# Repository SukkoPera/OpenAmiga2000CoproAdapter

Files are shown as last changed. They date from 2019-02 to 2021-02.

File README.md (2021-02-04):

# OpenAmiga2000CoproAdapter
OpenAmiga2000CoproAdapter is an Open Hardware adapter that allows installing the main processor of a Commodore Amiga 2000 computer in the co-processor slot.

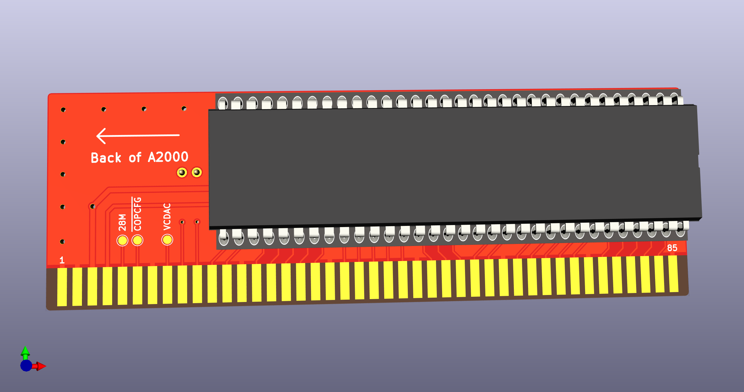
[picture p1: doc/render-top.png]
Board


### Summary
OpenAmiga2000CoproAdapter is an adapter that allows installing the main processor of a Commodore Amiga 2000 computer in the co-processor slot, based on [work by kipper2k](http://eab.abime.net/showthread.php?t=89604). It is mainly useful to mount TerribleFire and other accelerator cards without having to remove the floppy drive tray and without having them bump into your MegaChip, in case.

The adapter is very similar to the original, except that I skipped the INT7 and the A600 NMI circuits. Those are not needed for TerribleFire cards and for most other boards (I think they are for Vampires only). I carried over the INT2/OVR header, since the former is needed for the TF530. I have also introduced solder jumpers for the FR0-2 signals: those are not connected on kipper2k's board, I don't know why and it works well anyway, but I thought they wouldn't hurt as they will be open by default.

You may be able to install this without removing the original CPU by cutting the E jumper and closing the BOSS one.

This is a slightly expensive board to manufacture because it exceeds the 10x10cm limit that cheap fab houses impose, because it needs gold-plating for better contact and resistance to repeated insertions/removals, and because the edge connector should be beveled to ease insertion. These are the recommended settings if you want to get the boards made.

### Installation
**Please be very careful when plugging this board** in the co-processor slot: there is an arrow on the board, **it must point to the back of the Amiga**. Plugging this adapter backwards will damage your CPU/accelerator card, as some pins of the CPU slot carry +12V!

When this board is installed, most likely the original 68000 socket must be left empty unless you cut the E jumper and close the BOSS jumper, though this ultimately depends on the particular card you will be installing.

### License
The OpenAmiga2000CoproAdapter documentation, including the design itself, is copyright &copy; SukkoPera 2018-2019.

OpenAmiga2000CoproAdapter is Open Hardware licensed under the [CERN OHL v. 1.2](http://ohwr.org/cernohl).

You may redistribute and modify this documentation under the terms of the CERN OHL v.1.2. This documentation is distributed *as is* and WITHOUT ANY EXPRESS OR IMPLIED WARRANTIES whatsoever with respect to its functionality, operability or use, including, without limitation, any implied warranties OF MERCHANTABILITY, SATISFACTORY QUALITY, FITNESS FOR A PARTICULAR PURPOSE or infringement. We expressly disclaim any liability whatsoever for any direct, indirect, consequential, incidental or special damages, including, without limitation, lost revenues, lost profits, losses resulting from business interruption or loss of data, regardless of the form of action or legal theory under which the liability may be asserted, even if advised of the possibility or likelihood of such damages.

A copy of the full license is included in file [LICENSE.pdf](LICENSE.pdf), please refer to it for applicable conditions. In order to properly deal with its terms, please see file [LICENSE_HOWTO.pdf](LICENSE_HOWTO.pdf).

The contact points for information about manufactured Products (see section 4.2) are listed in file [PRODUCT.md](PRODUCT.md).

Any modifications made by Licensees (see section 3.4.b) shall be recorded in file [CHANGES.md](CHANGES.md).

The Documentation Location of the original project is https://github.com/SukkoPera/OpenAmiga2000CoproAdapter/.

### Support the Project
Since the project is open you are free to get the PCBs made by your preferred manufacturer, however in case you want to support the development, you can order them from PCBWay through this link:

PCB from PCBWay (https://www.pcbway.com/project/shareproject/OpenAmiga2000CoproAdapter_V3.html)

You get cheap, professionally-made and good quality PCBs, I get some credit that will help with this and [other projects](https://www.pcbway.com/project/member/shareproject/?bmbid=41100). You won't even have to worry about the various PCB options, it's all pre-configured for you!

Also, if you still have to register to that site, [you can use this link](https://www.pcbway.com/setinvite.aspx?inviteid=41100) to get some bonus initial credit (and yield me some more).

Again, if you want to use another manufacturer, feel free to, don't feel obligated :). But then you can buy me a coffee if you want:

<a href='https://ko-fi.com/L3L0U18L' target='_blank'>Buy Me a Coffee at ko-fi.com</a>

### Get Help
If you need help or have questions, you can join [the official Telegram group](https://t.me/joinchat/HUHdWBC9J9JnYIrvTYfZmg).

### Thanks
Thanks to kipper2k, of course :).

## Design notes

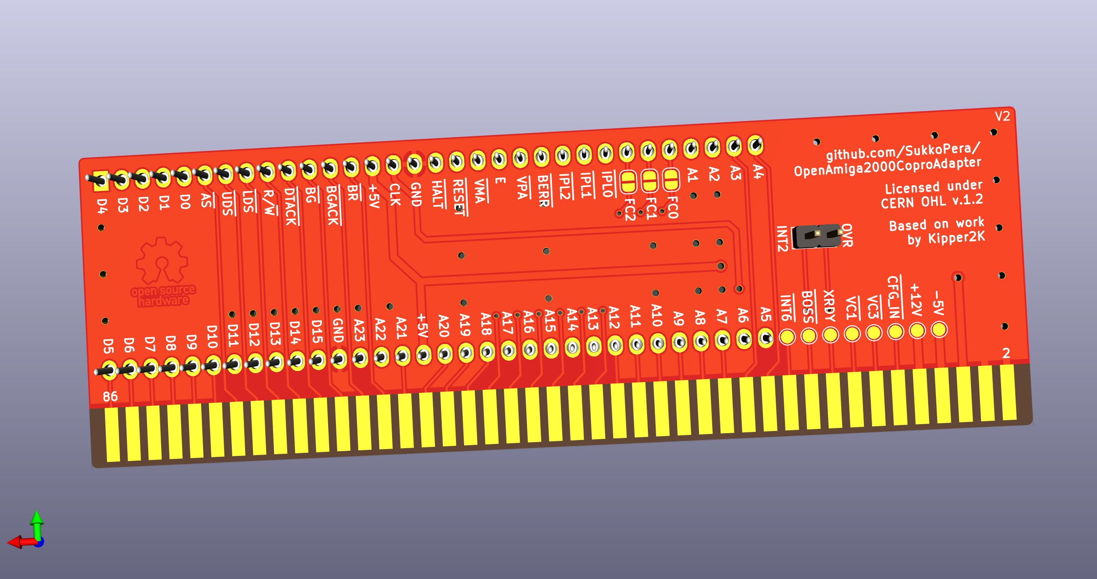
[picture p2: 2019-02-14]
doc/render-bottom.png

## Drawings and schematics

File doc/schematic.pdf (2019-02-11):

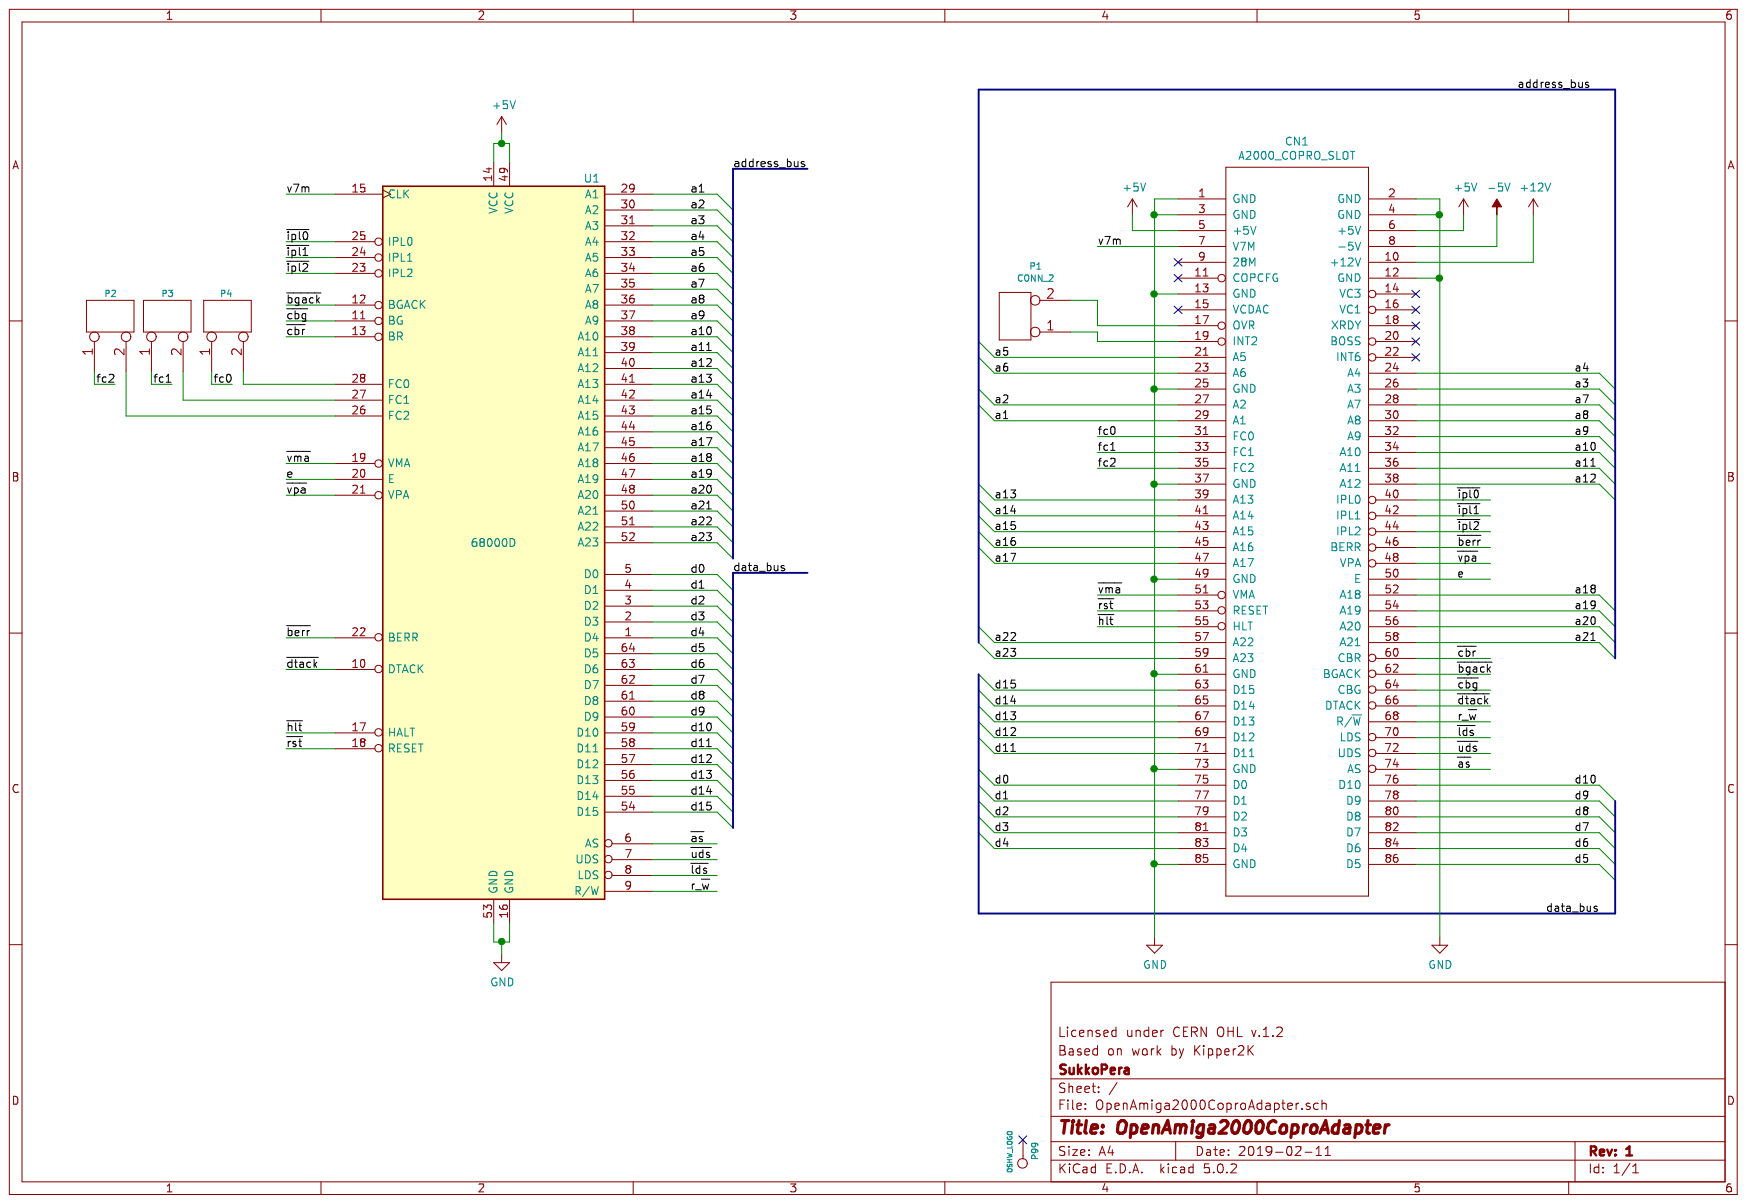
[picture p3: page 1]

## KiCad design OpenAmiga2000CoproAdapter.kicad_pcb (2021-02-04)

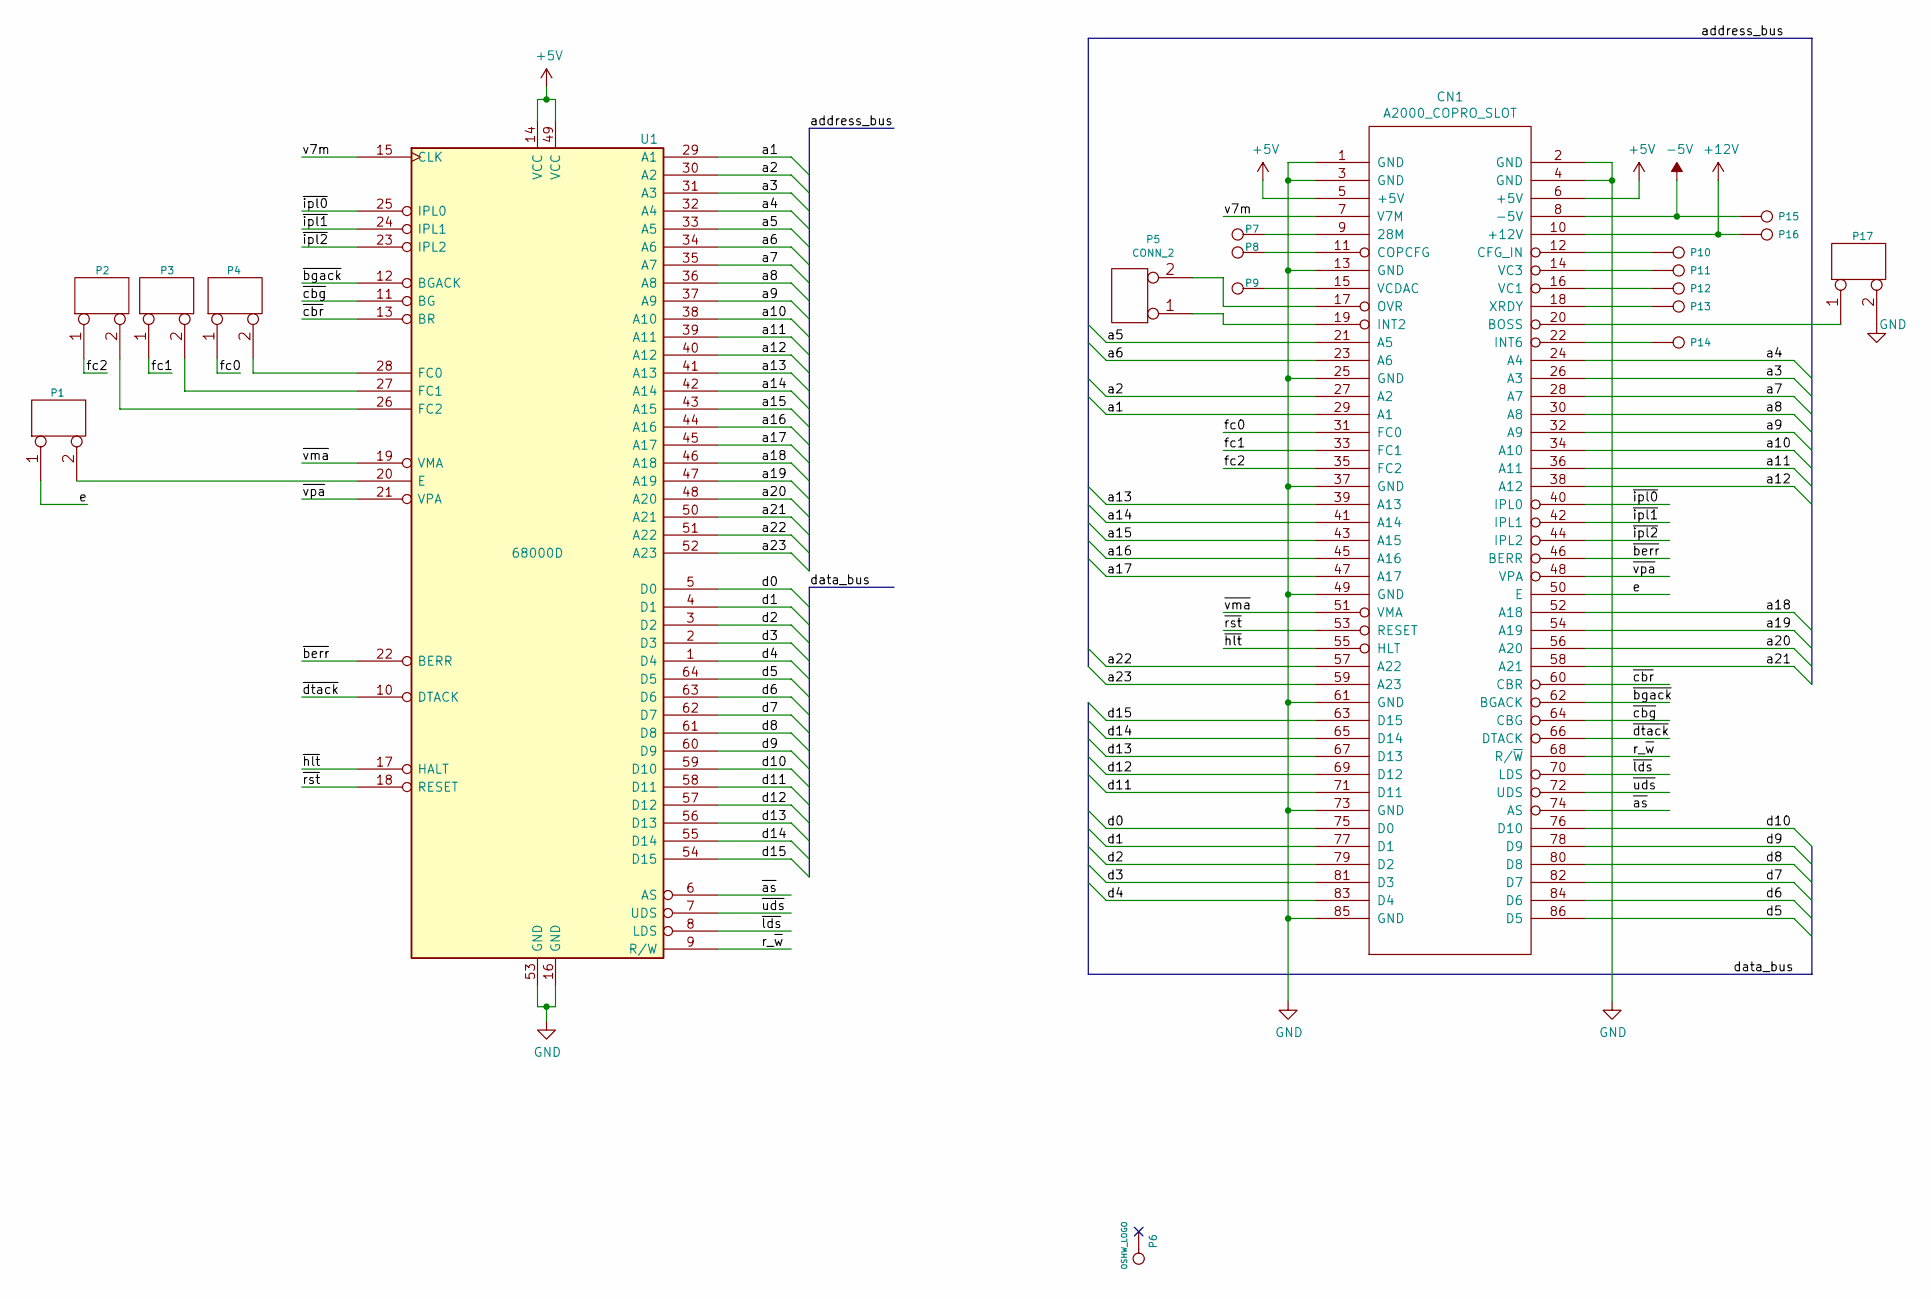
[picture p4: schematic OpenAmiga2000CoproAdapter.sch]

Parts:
CN1: A2000_COPRO_SLOT
P1: CONN_2; SolderJumper-2_P1.3mm_Bridged_RoundedPad1.0x1.5mm
P2, P3, P4, P17: CONN_2; SolderJumper-2_P1.3mm_Open_RoundedPad1.0x1.5mm
P5: CONN_2; PinHeader_1x02_P2.54mm_Vertical
P6: OSHW_LOGO; OSHW-Logo_7.5x8mm_Copper
P7, P8, P9, P10, P11, P12, P13, P14, P15, P16: CONN_1; TestPoint_Pad_D1.5mm
U1: 68000D; DIP-64_W22.86mm_Socket_LongPads

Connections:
+5V: CN1.5 (+5V), CN1.6 (+5V), U1.14 (VCC), U1.49 (VCC)
+12V: CN1.10 (+12V), P16.1
-5V: CN1.8 (-5V), P15.1
/a1: CN1.29 (A1), U1.29 (A1)
/a2: CN1.27 (A2), U1.30 (A2)
/a3: CN1.26 (A3), U1.31 (A3)
/a4: CN1.24 (A4), U1.32 (A4)
/a5: CN1.21 (A5), U1.33 (A5)
/a6: CN1.23 (A6), U1.34 (A6)
/a7: CN1.28 (A7), U1.35 (A7)
/a8: CN1.30 (A8), U1.36 (A8)
/a9: CN1.32 (A9), U1.37 (A9)
/a10: CN1.34 (A10), U1.38 (A10)
/a11: CN1.36 (A11), U1.39 (A11)
/a12: CN1.38 (A12), U1.40 (A12)
/a13: CN1.39 (A13), U1.41 (A13)
/a14: CN1.41 (A14), U1.42 (A14)
/a15: CN1.43 (A15), U1.43 (A15)
/a16: CN1.45 (A16), U1.44 (A16)
/a17: CN1.47 (A17), U1.45 (A17)
/a18: CN1.52 (A18), U1.46 (A18)
/a19: CN1.54 (A19), U1.47 (A19)
/a20: CN1.56 (A20), U1.48 (A20)
/a21: CN1.58 (A21), U1.50 (A21)
/a22: CN1.57 (A22), U1.51 (A22)
/a23: CN1.59 (A23), U1.52 (A23)
/d0: CN1.75 (D0), U1.5 (D0)
/d1: CN1.77 (D1), U1.4 (D1)
/d2: CN1.79 (D2), U1.3 (D2)
/d3: CN1.81 (D3), U1.2 (D3)
/d4: CN1.83 (D4), U1.1 (D4)
/d5: CN1.86 (D5), U1.64 (D5)
/d6: CN1.84 (D6), U1.63 (D6)
/d7: CN1.82 (D7), U1.62 (D7)
/d8: CN1.80 (D8), U1.61 (D8)
/d9: CN1.78 (D9), U1.60 (D9)
/d10: CN1.76 (D10), U1.59 (D10)
/d11: CN1.71 (D11), U1.58 (D11)
/d12: CN1.69 (D12), U1.57 (D12)
/d13: CN1.67 (D13), U1.56 (D13)
/d14: CN1.65 (D14), U1.55 (D14)
/d15: CN1.63 (D15), U1.54 (D15)
/e: CN1.50 (E), P1.1
/fc0: CN1.31 (FC0), P4.1
/fc1: CN1.33 (FC1), P3.1
/fc2: CN1.35 (FC2), P2.1
/r_~w: CN1.68 (R/~W), U1.9 (R/W)
/v7m: CN1.7 (V7M), U1.15 (CLK)
/~as: CN1.74 (AS), U1.6 (AS)
/~berr: CN1.46 (BERR), U1.22 (BERR)
/~bgack: CN1.62 (BGACK), U1.12 (BGACK)
/~cbg: CN1.64 (CBG), U1.11 (BG)
/~cbr: CN1.60 (CBR), U1.13 (BR)
/~dtack: CN1.66 (DTACK), U1.10 (DTACK)
/~hlt: CN1.55 (HLT), U1.17 (HALT)
/~ipl0: CN1.40 (IPL0), U1.25 (IPL0)
/~ipl1: CN1.42 (IPL1), U1.24 (IPL1)
/~ipl2: CN1.44 (IPL2), U1.23 (IPL2)
/~lds: CN1.70 (LDS), U1.8 (LDS)
/~rst: CN1.53 (RESET), U1.18 (RESET)
/~uds: CN1.72 (UDS), U1.7 (UDS)
/~vma: CN1.51 (VMA), U1.19 (VMA)
/~vpa: CN1.48 (VPA), U1.21 (VPA)
GND: CN1.1 (GND), CN1.2 (GND), CN1.3 (GND), CN1.4 (GND), CN1.13 (GND), CN1.25 (GND), CN1.37 (GND), CN1.49 (GND), CN1.61 (GND), CN1.73 (GND), CN1.85 (GND), P17.2 (PM), U1.16 (GND), U1.53 (GND)
unnamed: CN1.9 (28M), P7.1
unnamed: CN1.11 (COPCFG), P8.1
unnamed: CN1.12 (CFG_IN), P10.1
unnamed: CN1.14 (VC3), P11.1
unnamed: CN1.15 (VCDAC), P9.1
unnamed: CN1.16 (VC1), P12.1
unnamed: CN1.17 (OVR), P5.2 (PM)
unnamed: CN1.18 (XRDY), P13.1
unnamed: CN1.19 (INT2), P5.1
unnamed: CN1.20 (BOSS), P17.1
unnamed: CN1.22 (INT6), P14.1
unnamed: P1.2 (PM), U1.20 (E)
unnamed: P2.2 (PM), U1.26 (FC2)
unnamed: P3.2 (PM), U1.27 (FC1)
unnamed: P4.2 (PM), U1.28 (FC0)

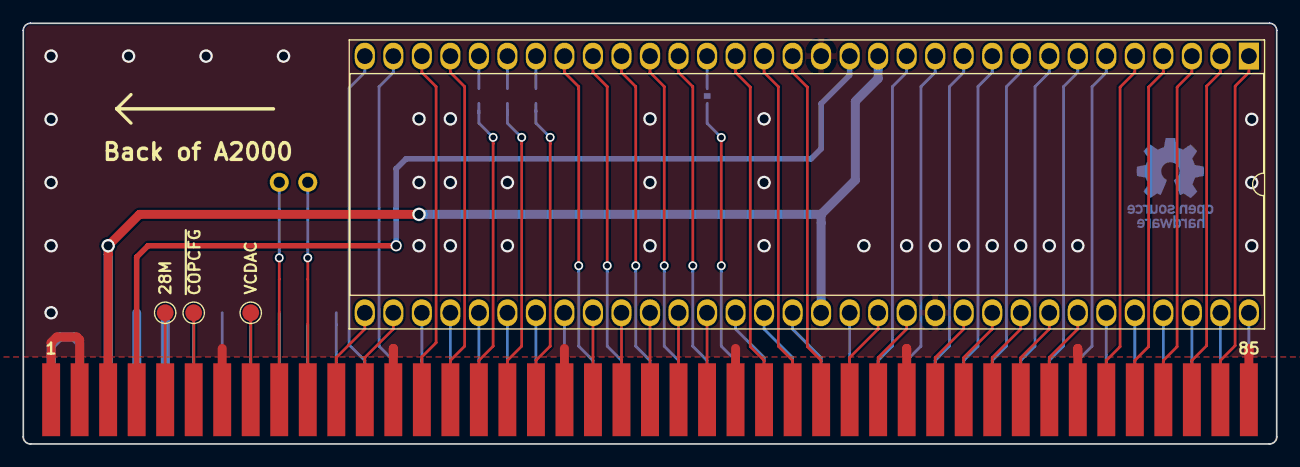
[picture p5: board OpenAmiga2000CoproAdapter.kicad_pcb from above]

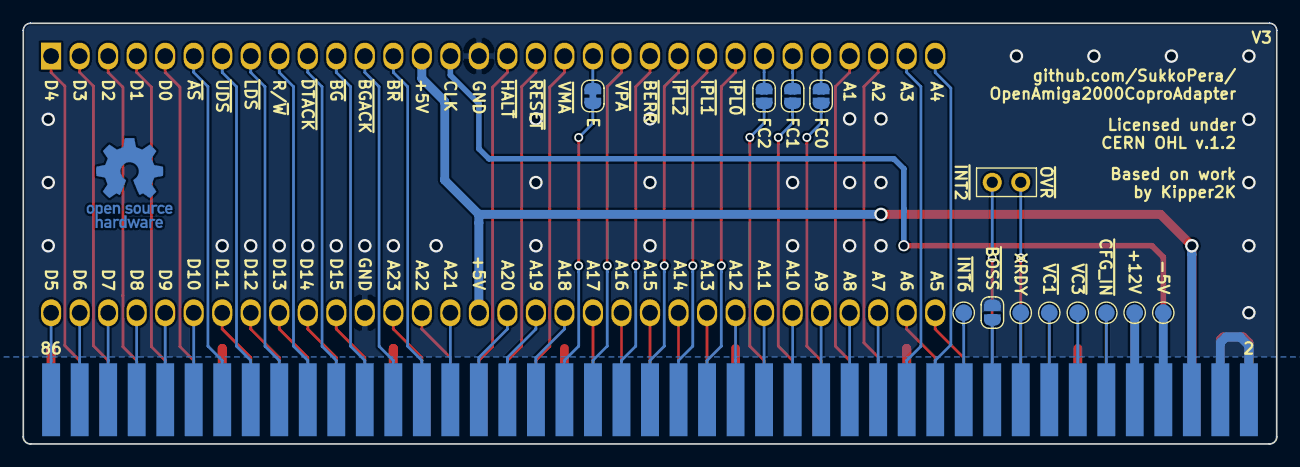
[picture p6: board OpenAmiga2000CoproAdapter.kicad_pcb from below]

Board: 2 copper layers, 111.6 x 37.5 mm, 19 parts (14 on the bottom side), 79 nets.

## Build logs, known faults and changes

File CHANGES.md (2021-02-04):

## CHANGES

Any modifications to the OpenAmiga2000CoproAdapter design and documentation made by any Licensee MUST be noted in this file, as per *section 3.4.b* of the [license](LICENSE.pdf).

### 02/02/2021 - Matt Harlum
* Changed /BOSS testpoint to a jumper
* Added a closed smd jumper for E clock

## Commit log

2018-10-28 Initial commit, V1 sent to production
    [OpenAmiga2000CoproAdapter.kicad_pcb, OpenAmiga2000CoproAdapter.sch]
2018-10-29 Add silkscreen hint for the FCx lines
    [OpenAmiga2000CoproAdapter.kicad_pcb]
2018-10-30 Nicer placement of +5V/Clock traces
    [OpenAmiga2000CoproAdapter.kicad_pcb]
2018-11-02 Improve 3D view
    [OpenAmiga2000CoproAdapter.kicad_pcb]
2019-02-11 Add license info
    [OpenAmiga2000CoproAdapter.kicad_pcb, OpenAmiga2000CoproAdapter.sch]
2019-02-12 Add pin names on silkscreen Yeah, I like this!
    [OpenAmiga2000CoproAdapter.kicad_pcb]
2019-02-14 Treat CONFIG_IN pin properly
    [OpenAmiga2000CoproAdapter.kicad_pcb, OpenAmiga2000CoproAdapter.sch]
2019-02-14 Add test points for *all* the signals available on the connector
    [OpenAmiga2000CoproAdapter.kicad_pcb, OpenAmiga2000CoproAdapter.sch]
2019-02-14 Minor cosmetic fixes
    [OpenAmiga2000CoproAdapter.kicad_pcb]
2019-02-14 More minor cosmetic fixes
    [OpenAmiga2000CoproAdapter.kicad_pcb]
2019-03-21 Make board ~0.4mm narrower for a better fit
    [OpenAmiga2000CoproAdapter.kicad_pcb]
2019-07-09 Ready for V3
    [OpenAmiga2000CoproAdapter.kicad_pcb]
2021-02-02 Add jumpers for E, Boss
    * Cutting the E jumper and closing the BOSS one will allow the card to work without removing the original cpu
    * Closing BOSS is required for B2000 DMA to work, buster doesn't route BR to the copro slot unless /BOSS is asserted
    [OpenAmiga2000CoproAdapter.kicad_pcb, OpenAmiga2000CoproAdapter.sch]

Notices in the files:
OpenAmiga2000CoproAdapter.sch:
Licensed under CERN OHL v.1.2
